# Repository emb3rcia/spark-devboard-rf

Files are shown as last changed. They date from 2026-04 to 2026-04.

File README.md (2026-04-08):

# spark-debug
# Navigation
- [About project](#about-project)
  - [Motivation for the project](#motivation-for-the-project)
  - [Humorous additions](#humorous-additions)
  - [Pin tables](#pin-tables)
  - [Development tools](#development-tools)
  - [Features](#features)
- [Images](#images)
- [License](#license)

# About project

spark-devboard-rf is RF focused devboard based on ESPRESSIF ESP32-WROVER-IE-N16R8 allowing Wi-Fi b/g/n, Bluetooth 4.2 Classic and Bluetooth 4.2 BLE communication using external u.FL antena

## Motivation for the project

spark-devboard-rf was created from boreness, but also as a stepping stone before using the same module in upcoming audio player of mine

## Pin functions

Pin functions are written on back of the PCB. Alternate functions can be found in [this datasheet](https://documentation.espressif.com/esp32-wrover-e_esp32-wrover-ie_datasheet_en.pdf)

## Usage

You use it as any other developement board. Important caveats are programming and powering the board.

### Programming

You need to program this board via UART interface specified on the back side of PCB. To enter flashing mode you need to hold BOOT button during power on or resetting the board

### Powering

Board can be either powered by 5x 3.3V pins on board, where you need to supply minimum of 500 mA for board to work properly, or via USB-C power-only port on board, where the pins become 3.3V output. **It is important to make sure that you are powering the board from only one supply method at the time**

## Directory overview

- 3D file of PCB is available in `/3D`
- KiCad project files are available in `/KiCad Project Files`
- Gerber files are available in `/Gerbers`

## Development tools

- KiCad for EDA work

## Features

- ESP32 module with 8MB PSRAM and 16MB flash
- u.FL antenna slot
- USB-C port for power
- Integrated 3.3V LDO

# Images

Schematic

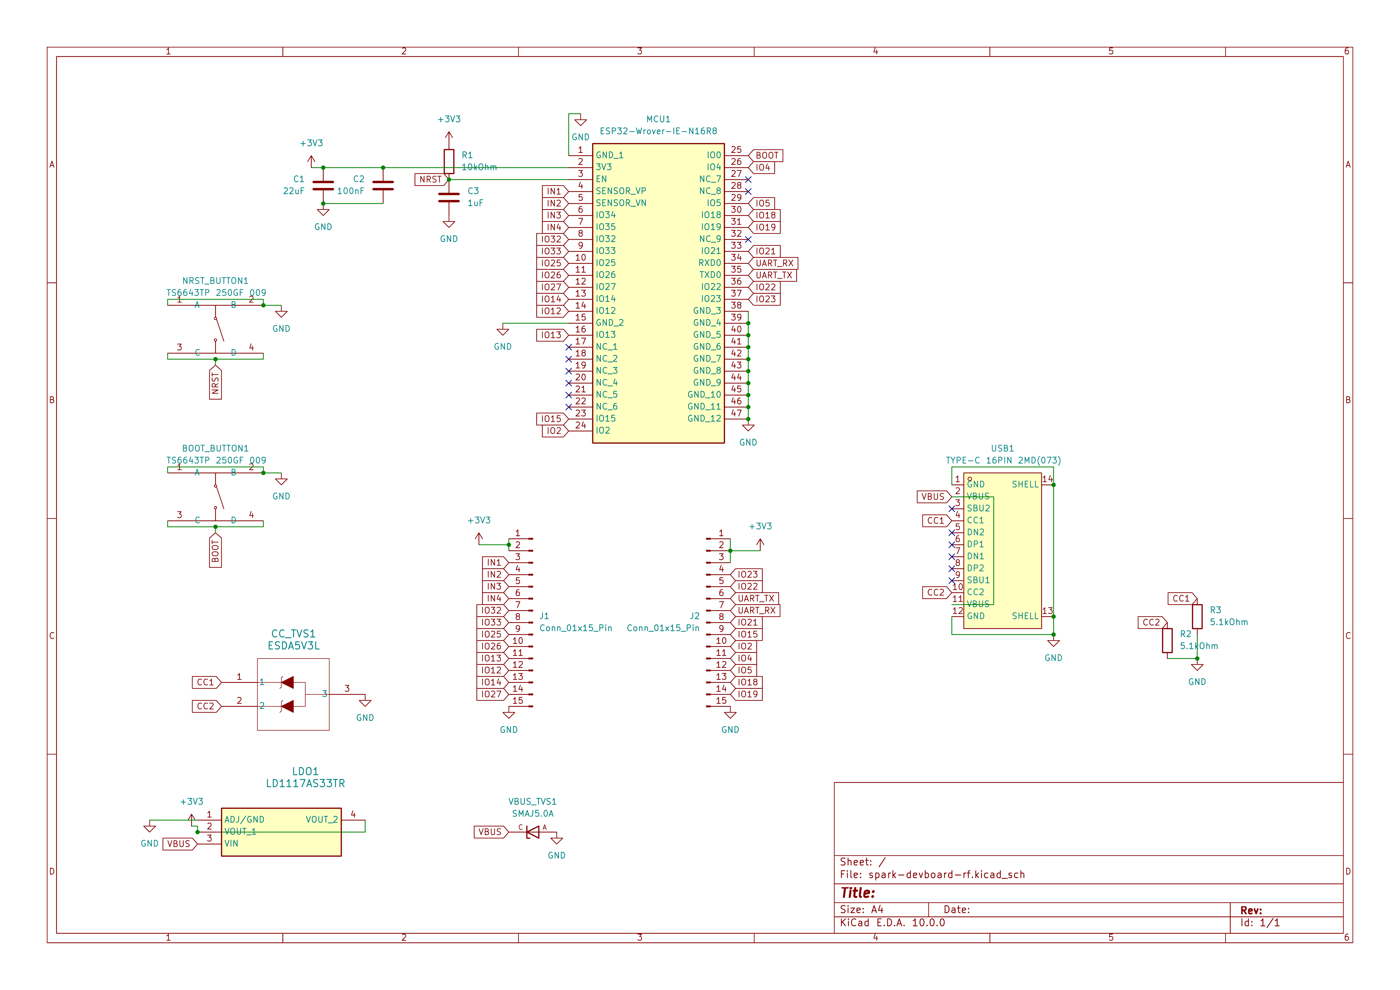
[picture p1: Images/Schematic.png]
schematic


PCB editor view

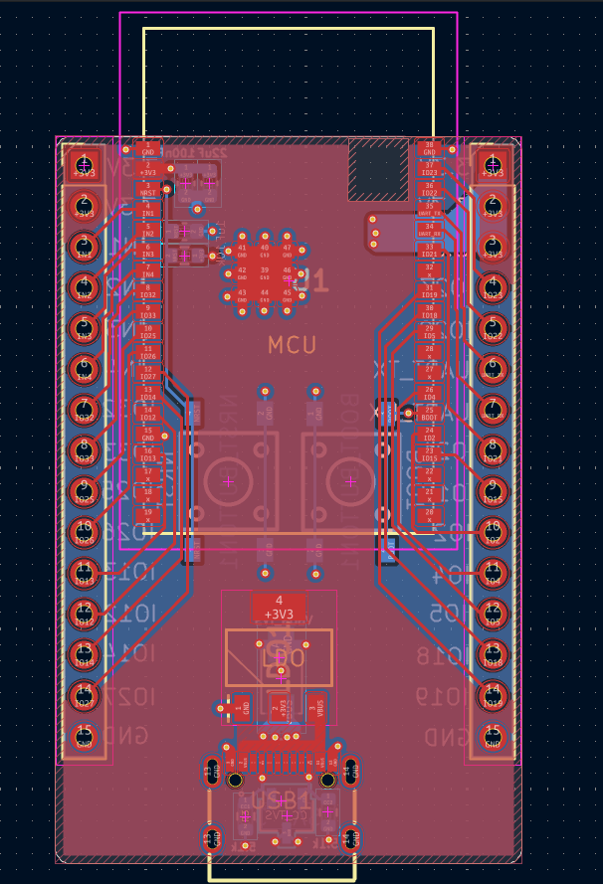
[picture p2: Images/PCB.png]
pcb editor view


3D viewer top side

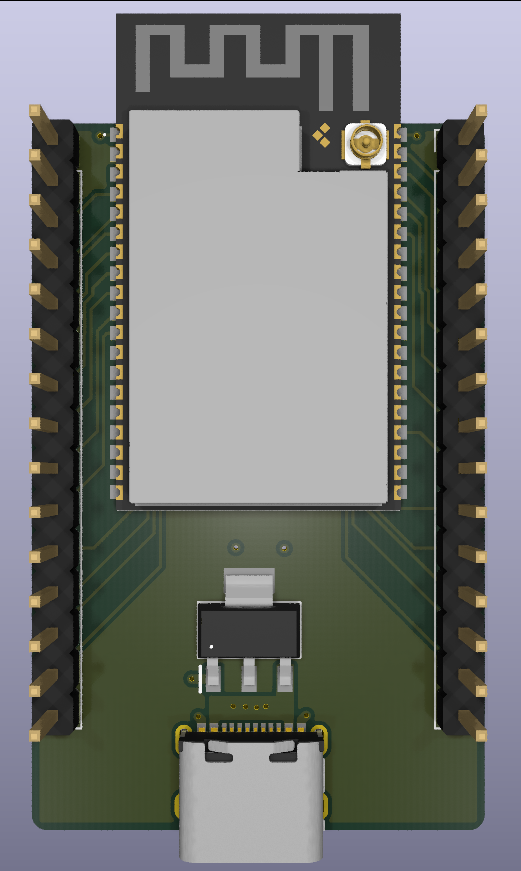
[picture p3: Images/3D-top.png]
3d top side


3D viewer bottom side

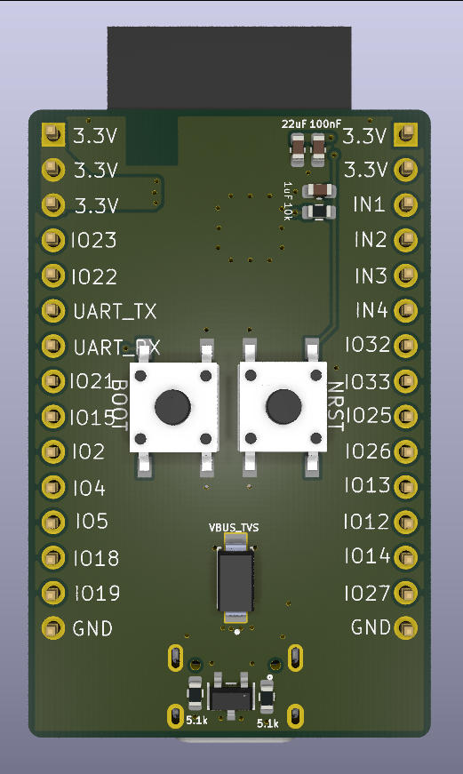
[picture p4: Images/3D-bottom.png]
3d bottom side


# License

## PCB / Schematic License

All files in `/PCB`, `/Schematic` and `/Gerbers` folders and their subsequent subfolders are licensed under the CERN Open Hardware License v2 (Weakly Reciprocal).

See `/Licenses/CERN-OHL.txt` for full terms.

## 3D files, images and documentation License

All files in `/3D`, `/Images` and `/Docs` folders and their subsequent subfolders are licensed under the CC-BY 4.0 License.

See `/Licenses/CC-BY-4.0.txt` for full terms

# BOM

|Name |Purpose |Quantity|Total Cost (USD)|Link |Distributor|
|---|---|---|---|---|---|
|PCB |PCB |5 |2.10 | |JLCPCB |
|MOLEX 206994-0100 |Antenna for connectivity|1 |2.38 |https://www.tme.eu/pl/details/2069940100/anteny-wifi-bluetooth/molex/206994-0100/ |TME |
|ESP32-WROVER-E-N16R8 |MCU module |1 |6.40 |https://www.tme.eu/pl/details/esp32-wrover-e-16/moduly-iot-wifi-bluetooth/espressif/esp32-wrover-e-n16r8/|TME |
|SHOU HAN TYPE-C 16PIN 2MD(073)|USB-C power port |1 |0.00 |https://www.lcsc.com/product-detail/C2765186.html?s_z=n_C2765186 |LCSC |

© 2026 emb3rcia

Hardware: CERN OHL v2
3D & Images: CC BY 4.0

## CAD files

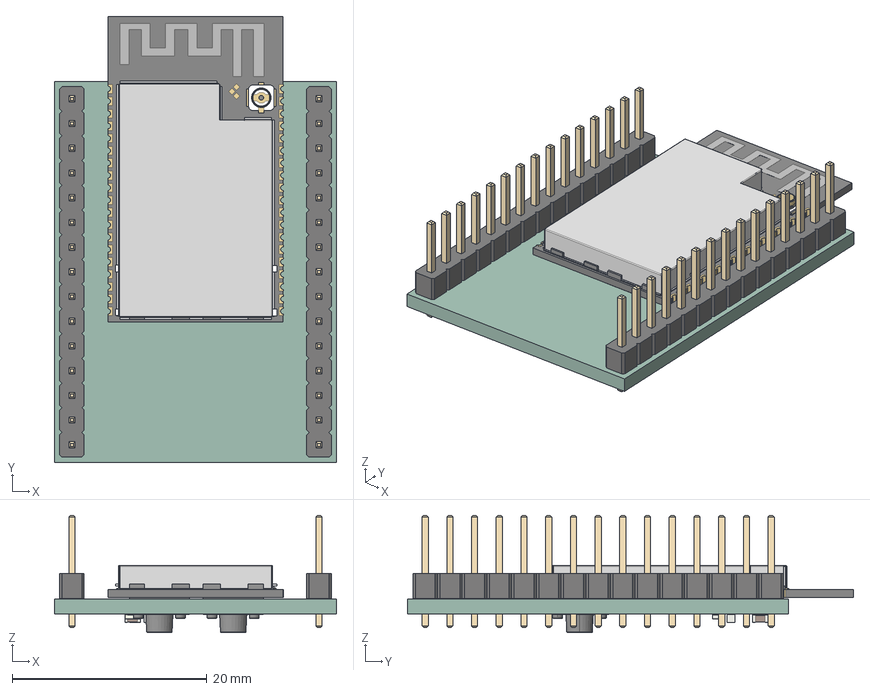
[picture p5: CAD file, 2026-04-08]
3D/spark-devboard-rf.step
29.0 x 45.8 x 12.1 mm
PinHeader_1x15_P2.54mm_Vertical x 2
ESP32-Wrover-IE-N16R8
SW-SMD_4P-L6.2-W6.0-H5-P4.50-LS9.0 x 2
R_0603_1608Metric
C_0603_1608Metric x 3
spark-devboard-rf_PCB

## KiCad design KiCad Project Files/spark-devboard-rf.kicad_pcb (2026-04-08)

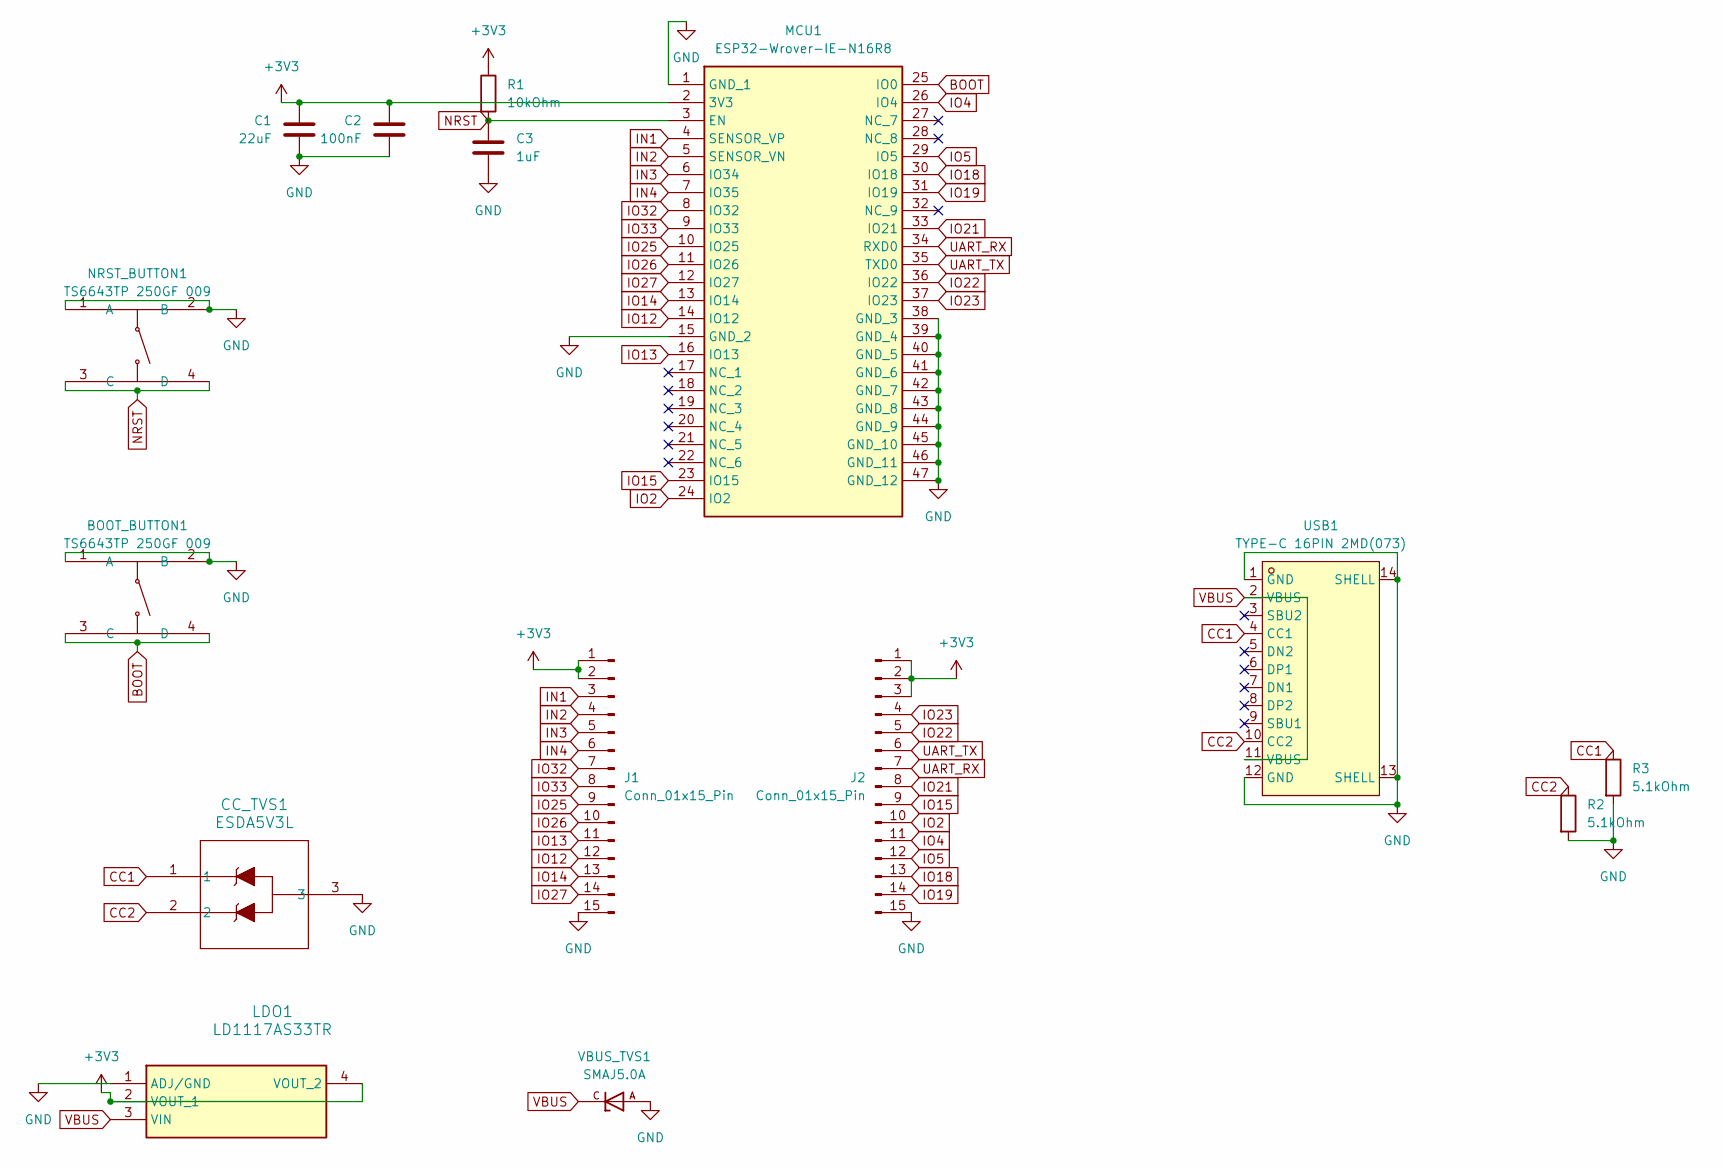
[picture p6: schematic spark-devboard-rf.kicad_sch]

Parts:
BOOT_BUTTON1: TS6643TP 250GF 009; SW-SMD_4P-L6.2-W6.0-P4.50-LS9.0; LCSC Part C5342967
C1: 22uF; C_0603_1608Metric
C2: 100nF; C_0603_1608Metric
C3: 1uF; C_0603_1608Metric
CC_TVS1: ESDA5V3L; SOT-23_STM
J1, J2: Conn_01x15_Pin; PinHeader_1x15_P2.54mm_Vertical
LDO1: LD1117AS33TR; SOT230P700X190-4N; Manufacturer_Part_Number LD1117AS33TR; Mouser Part Number 511-LD1117AS33
MCU1: ESP32-Wrover-IE-N16R8; ESP32WroverIEN16R8; Manufacturer_Part_Number ESP32-Wrover-IE-N16R8; Mouser Part Number 356-ESP32WRVIE2864UC
NRST_BUTTON1: TS6643TP 250GF 009; SW-SMD_4P-L6.2-W6.0-P4.50-LS9.0; LCSC Part C5342967
R1: 10kOhm; R_0603_1608Metric
R2, R3: 5.1kOhm; R_0603_1608Metric
USB1: TYPE-C 16PIN 2MD(073); USB-C-SMD_TYPE-C-6PIN-2MD-073; LCSC Part C2765186
VBUS_TVS1: SMAJ5.0A; DIOM4325X250N; PARTREV S2102

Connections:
+3V3: C1.1, C2.1, J1.1, J1.2, J2.1, J2.2, J2.3, LDO1.2 (VOUT_1), LDO1.4 (VOUT_2), MCU1.2 (3V3), R1.1
BOOT: BOOT_BUTTON1.3 (C), BOOT_BUTTON1.4 (D), MCU1.25 (IO0)
CC1: CC_TVS1.1, R3.1, USB1.4 (CC1)
CC2: CC_TVS1.2, R2.1, USB1.10 (CC2)
GND: BOOT_BUTTON1.1 (A), BOOT_BUTTON1.2 (B), C1.2, C2.2, C3.2, CC_TVS1.3, J1.15, J2.15, LDO1.1 (ADJ/GND), MCU1.1 (GND_1), MCU1.15 (GND_2), MCU1.38 (GND_3), MCU1.39 (GND_4), MCU1.40 (GND_5), MCU1.41 (GND_6), MCU1.42 (GND_7), MCU1.43 (GND_8), MCU1.44 (GND_9), MCU1.45 (GND_10), MCU1.46 (GND_11), MCU1.47 (GND_12), NRST_BUTTON1.1 (A), NRST_BUTTON1.2 (B), R2.2, R3.2, USB1.1 (GND), USB1.12 (GND), USB1.13 (SHELL), USB1.14 (SHELL), VBUS_TVS1.A
IN1: J1.3, MCU1.4 (SENSOR_VP)
IN2: J1.4, MCU1.5 (SENSOR_VN)
IN3: J1.5, MCU1.6 (IO34)
IN4: J1.6, MCU1.7 (IO35)
IO2: J2.10, MCU1.24 (IO2)
IO4: J2.11, MCU1.26 (IO4)
IO5: J2.12, MCU1.29 (IO5)
IO12: J1.12, MCU1.14 (IO12)
IO13: J1.11, MCU1.16 (IO13)
IO14: J1.13, MCU1.13 (IO14)
IO15: J2.9, MCU1.23 (IO15)
IO18: J2.13, MCU1.30 (IO18)
IO19: J2.14, MCU1.31 (IO19)
IO21: J2.8, MCU1.33 (IO21)
IO22: J2.5, MCU1.36 (IO22)
IO23: J2.4, MCU1.37 (IO23)
IO25: J1.9, MCU1.10 (IO25)
IO26: J1.10, MCU1.11 (IO26)
IO27: J1.14, MCU1.12 (IO27)
IO32: J1.7, MCU1.8 (IO32)
IO33: J1.8, MCU1.9 (IO33)
NRST: C3.1, MCU1.3 (EN), NRST_BUTTON1.3 (C), NRST_BUTTON1.4 (D), R1.2
UART_RX: J2.7, MCU1.34 (RXD0)
UART_TX: J2.6, MCU1.35 (TXD0)
VBUS: LDO1.3 (VIN), USB1.2 (VBUS), USB1.11 (VBUS), VBUS_TVS1.C

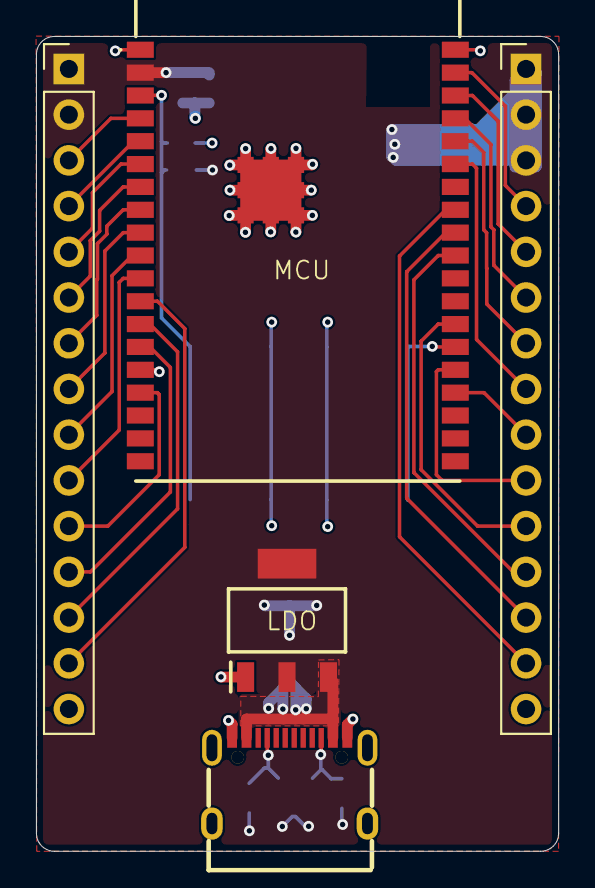
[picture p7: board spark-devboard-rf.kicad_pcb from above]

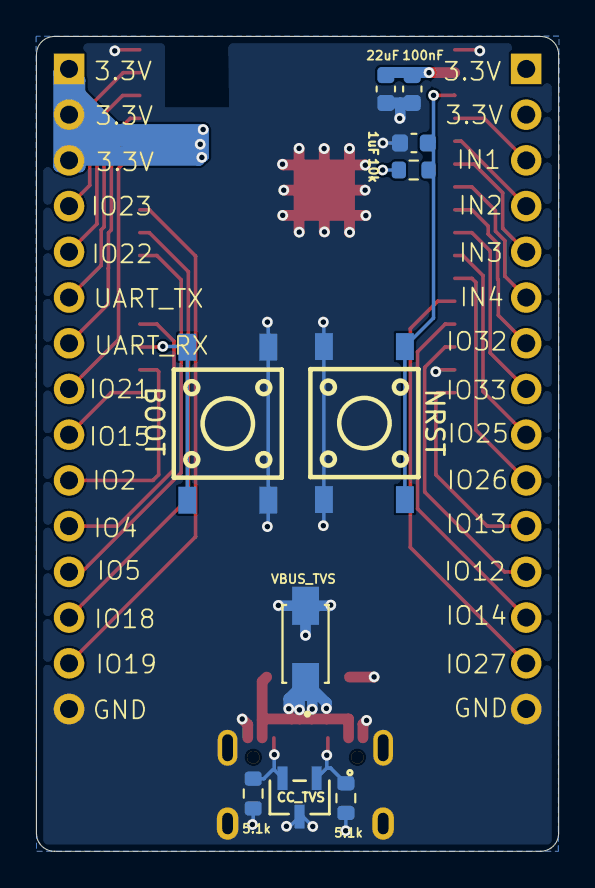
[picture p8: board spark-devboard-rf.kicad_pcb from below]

Board: 2 copper layers, 29.0 x 45.3 mm, 15 parts (10 on the bottom side), 30 nets.
